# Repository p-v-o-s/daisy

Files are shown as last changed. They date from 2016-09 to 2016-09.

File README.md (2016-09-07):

#daisy

## arrangement

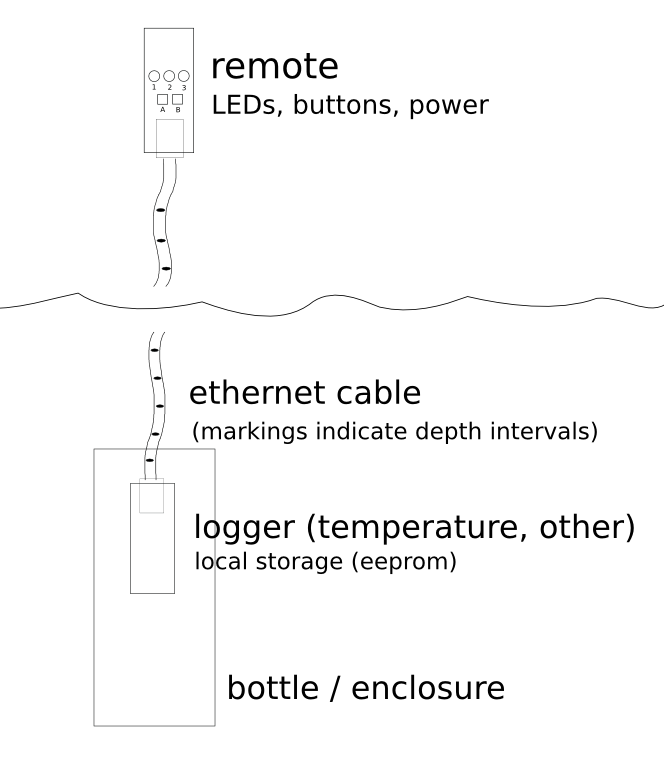
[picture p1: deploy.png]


# datalogger

Top:

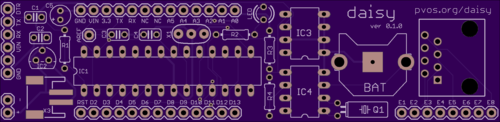
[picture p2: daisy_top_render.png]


Bottom:



- programmed via FTDI cable, board = "Arduino UNO"
- estimated < 100 microAmp sleep current
- DS1337 RTC with battery backup
- i2c EEPROM, 512KB storage
- RJ45 connector for 8-wire CAT-5,6,7 cable
- pin headers allow for patching RJ45 to digital / analog / power / ground
- JST header for battery power (or use remote)

# remote

Top:

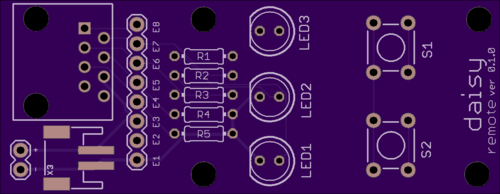
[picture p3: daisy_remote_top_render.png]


Bottom:

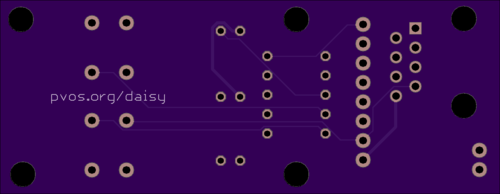
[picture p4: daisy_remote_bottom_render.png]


- RJ45 connector
- JST header for battery power (or use remote)
- RJ45 pins broken out via header for custom patching
- 3 LEDs connected to ethernet pins 1,2,3 (if placed)
- 2 momentary buttons connected to ethernet pins 4,5 (if placed)
- mounting holes 

# remote w/ display

Replaces LEDs with a 128x32 OLED display from Adafruit:

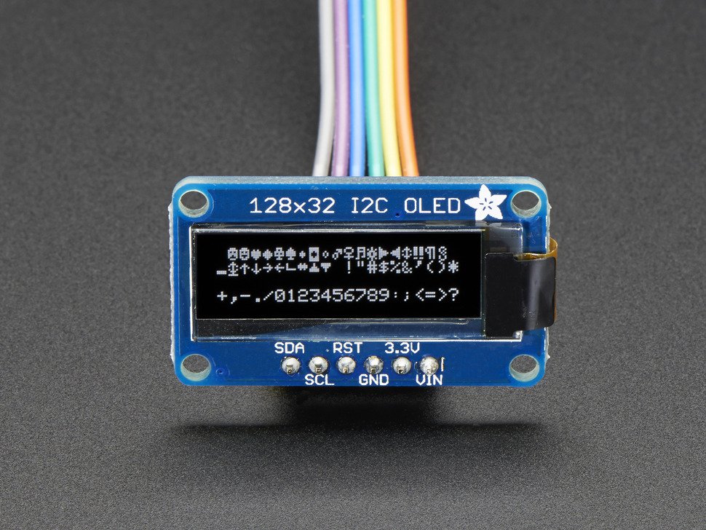
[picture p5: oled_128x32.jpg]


Top:

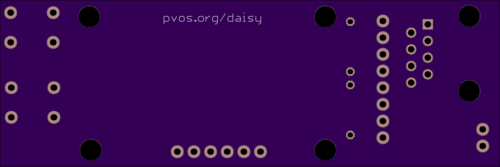
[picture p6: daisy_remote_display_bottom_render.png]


Bottom:

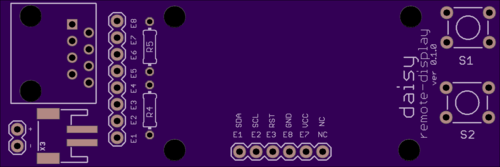
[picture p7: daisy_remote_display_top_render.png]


To hook up [Adafruit OLED display](https://www.adafruit.com/products/931):

- 3.3V  OLED VIN.
- GND to OLED ground (GND).
- I2C SCL (A5) to OLED SCL.
- I2C SDA (A4) to OLED SDA.
- digital 4 to OLED RST.
- these pins are marked on the remote-display board.  Proper relevant patching must be done on the logger, to match.

# ref

http://pinouts.ru/NetworkCables/ethernet_10_100_1000_pinout.shtml

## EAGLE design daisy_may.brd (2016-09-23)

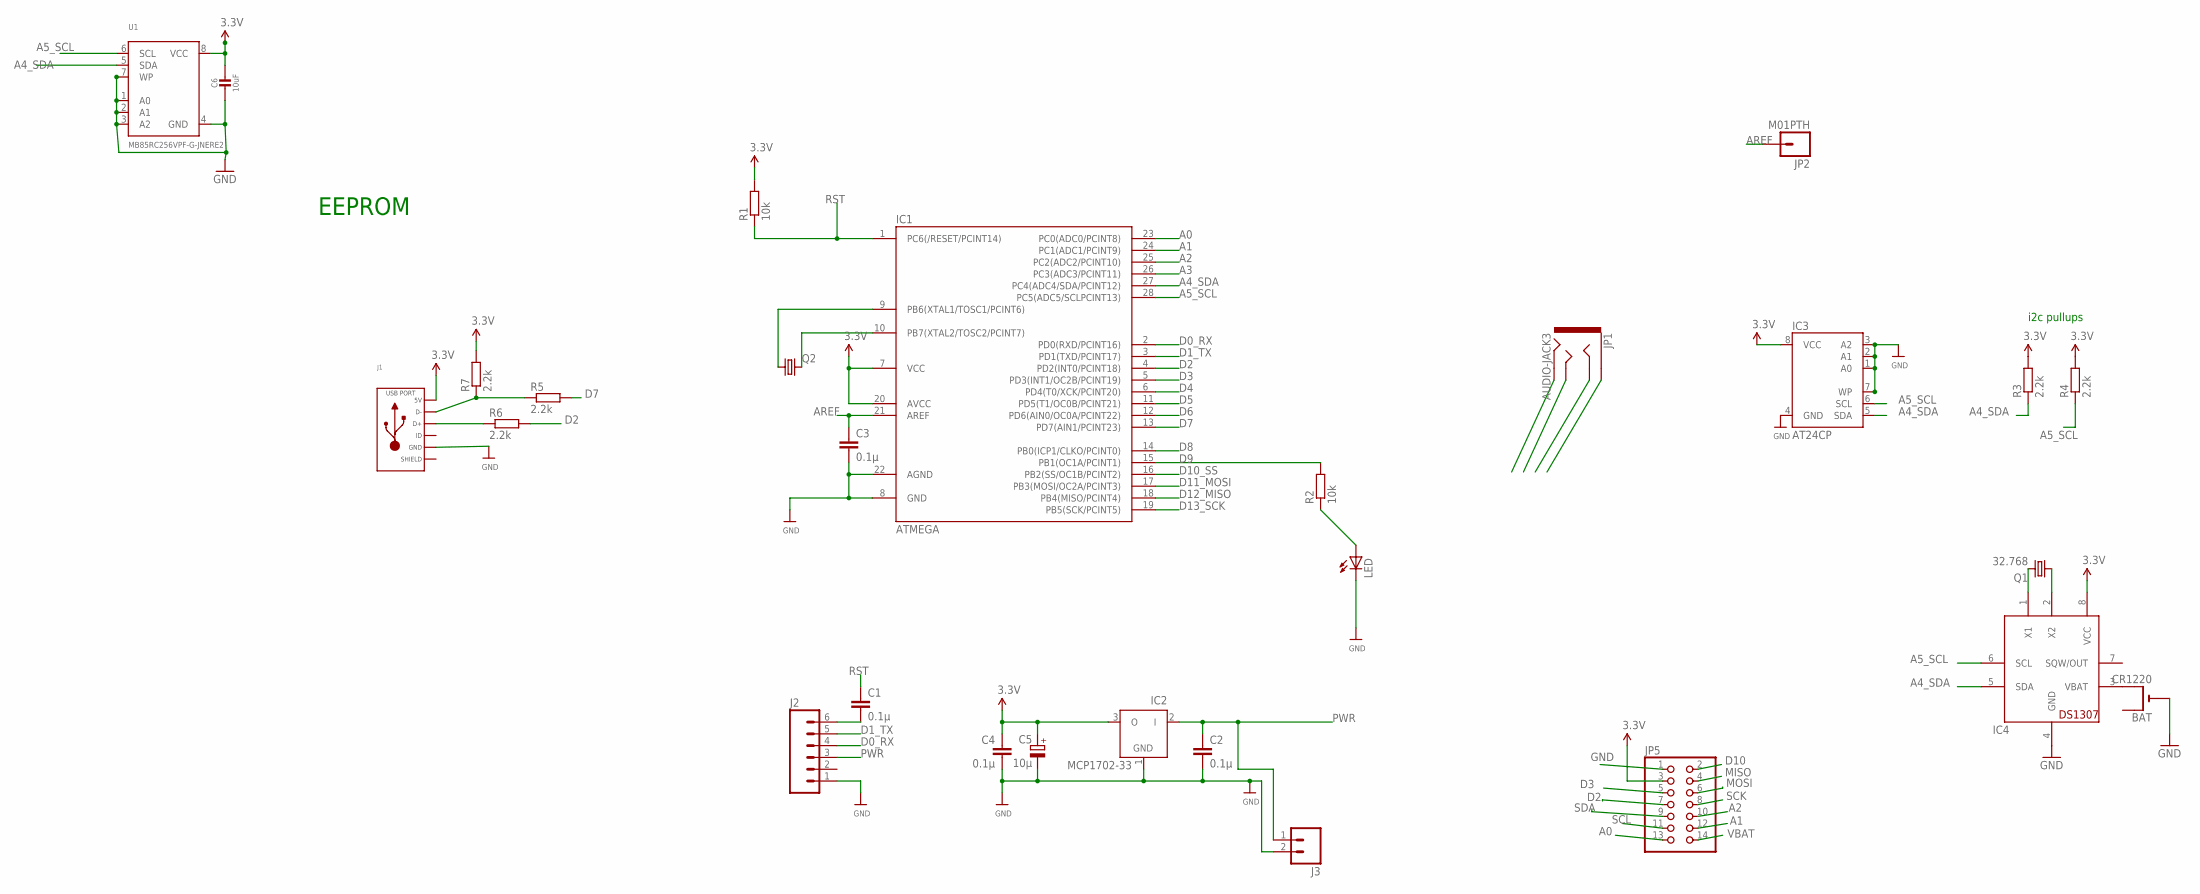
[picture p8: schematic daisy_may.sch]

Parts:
BAT: CR1220; CR1220-THM
C1, C2, C3, C4: 0.1µ; C025-024X044
C5: 10µ; E1,8-4
C6: 10uF; _0805MP
IC1: ATMEGA; DIL28-3
IC2: MCP1702-33; TO92
IC3: AT24CP; DIL08
IC4: DS1307; DIL08
J1: USB_MICRO_RIGHT; MICROUSB-RIGHT
J2: M06SILK_FEMALE_PTH; 1X06
J3: M02PTH; 1X02
JP1: AUDIO-JACK3; AUDIO-JACK-TRRS-SMD
JP2: M01PTH; 1X01
JP5: PINHD-2X7; 2X07
LED: LED3MM
Q1: 32.768; TC38H
Q2: CRYSTALHC49U70; HC49U70
R1, R2: 10k; 0204/7
R3, R4, R5, R6, R7: 2.2k; 0204/7
U1: MB85RC256VPF-G-JNERE2; SOIC8_208MIL

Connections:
A0: IC1.23 (PC0(ADC0/PCINT8)), JP5.13
A1: IC1.24 (PC1(ADC1/PCINT9)), JP5.12
A2: IC1.25 (PC2(ADC2/PCINT10)), JP5.10
A3: IC1.26 (PC3(ADC3/PCINT11))
A4_SDA: IC1.27 (PC4(ADC4/SDA/PCINT12)), IC3.5 (SDA), IC4.5 (SDA), R3.1, U1.5 (SDA)
A5_SCL: IC1.28 (PC5(ADC5/SCLPCINT13)), IC3.6 (SCL), IC4.6 (SCL), R4.1, U1.6 (SCL)
AREF: C3.1, IC1.21 (AREF), JP2.1
D0_RX: IC1.2 (PD0(RXD/PCINT16)), J2.4
D1_TX: IC1.3 (PD1(TXD/PCINT17)), J2.5
D2: IC1.4 (PD2(INT0/PCINT18)), JP5.7, R6.2
D3: IC1.5 (PD3(INT1/OC2B/PCINT19)), JP5.5
D4: IC1.6 (PD4(T0/XCK/PCINT20))
D5: IC1.11 (PD5(T1/OC0B/PCINT21))
D6: IC1.12 (PD6(AIN0/OC0A/PCINT22))
D7: IC1.13 (PD7(AIN1/PCINT23)), R5.2
D8: IC1.14 (PB0(ICP1/CLKO/PCINT0))
D9: IC1.15 (PB1(OC1A/PCINT1)), R2.2
D10: JP5.2
D10_SS: IC1.16 (PB2(SS/OC1B/PCINT2))
D11_MOSI: IC1.17 (PB3(MOSI/OC2A/PCINT3))
D12_MISO: IC1.18 (PB4(MISO/PCINT4))
D13_SCK: IC1.19 (PB5(SCK/PCINT5))
GND: BAT.-, C2.2, C3.2, C4.2, C5.-, C6.2, IC1.8 (GND), IC1.22 (AGND), IC2.1 (GND), IC3.1 (A0), IC3.2 (A1), IC3.3 (A2), IC3.4 (GND), IC3.7 (WP), IC4.4 (GND), J2.1, J3.2, JP5.1, LED.K (C), U1.1 (A0), U1.2 (A1), U1.3 (A2), U1.4 (GND), U1.7 (WP)
MISO: JP5.4
MOSI: JP5.6
unnamed: IC1.9 (PB6(XTAL1/TOSC1/PCINT6)), Q2.1
unnamed: LED.A, R2.1
unnamed: J1.2 (D-), R5.1, R7.1
unnamed: J1.3 (D+), R6.1
unnamed: IC4.1 (X1), Q1.2
unnamed: IC4.2 (X2), Q1.1
unnamed: C1.2, J2.6
unnamed: IC1.10 (PB7(XTAL2/TOSC2/PCINT7)), Q2.2
unnamed: BAT.+2 (+1), IC4.3 (VBAT)
PWR: C2.1, IC2.2 (I), J2.3, J3.1
RST: C1.1, IC1.1 (PC6(/RESET/PCINT14)), R1.1
SCK: JP5.8
SCL: JP5.11
SDA: JP5.9
SLD: J1.S1 (SLD), J1.S2 (SLD), J1.S3 (SLD), J1.S4 (SLD), J1.S5 (SLD), J1.S6 (SLD), J1.S7 (SLD), J1.S8 (SLD)
VBAT: JP5.14
VCC: C4.1, C5.+, C6.1, IC1.7 (VCC), IC1.20 (AVCC), IC2.3 (O), IC3.8 (VCC), IC4.8 (VCC), J1.1 (5V), JP5.3, R1.2, R3.2, R4.2, R7.2, U1.8 (VCC)

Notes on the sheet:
i2c pullups
EEPROM

Board: 2 copper layers, 28 parts (2 on the bottom side), 26 nets, no tracks yet.

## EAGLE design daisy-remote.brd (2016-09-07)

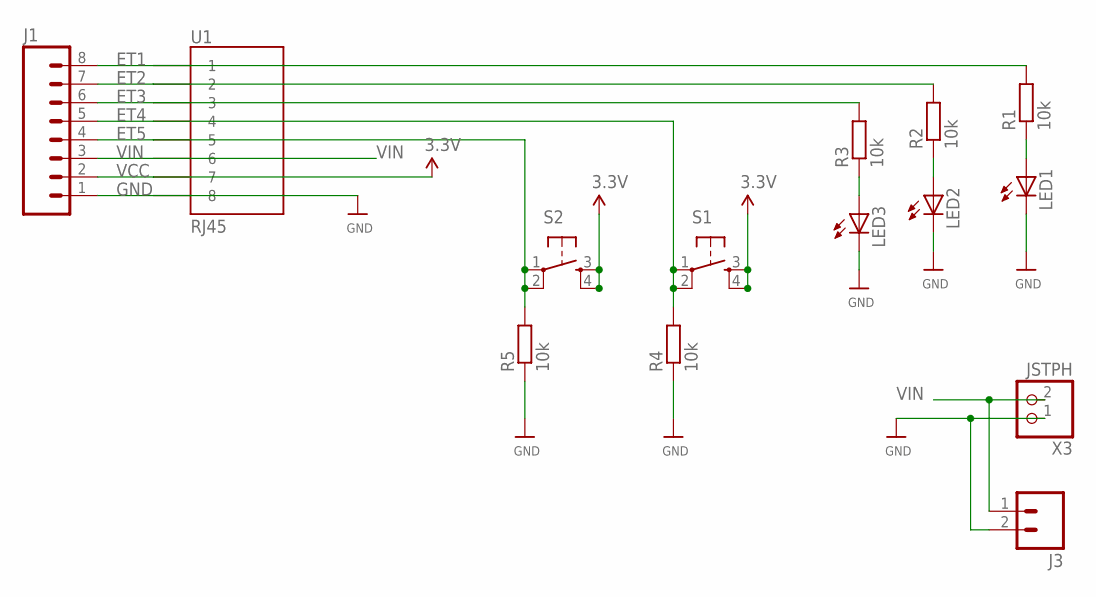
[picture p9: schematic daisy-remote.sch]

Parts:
J1: M08; 1X08_ROUND
J3: M02PTH; 1X02
LED1, LED2, LED3: LED5MM
R1, R2, R3, R4, R5: 10k; 0204/7
S1, S2: TAC_SWITCHPTH; TACTILE-PTH
U1: RJ45; RJ45-8
X3: JSTPH; JSTPH2

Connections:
ET1: J1.8, R1.2, U1.1
ET2: J1.7, R2.2, U1.2
ET3: J1.6, R3.2, U1.3
ET4: J1.5, R4.2, S1.1, S1.2, U1.4
ET5: J1.4, R5.2, S2.1, S2.2, U1.5
GND: J1.1, J3.2, LED1.K (C), LED2.K (C), LED3.K (C), R4.1, R5.1, U1.8, X3.1
unnamed: LED1.A, R1.1
unnamed: LED2.A, R2.1
unnamed: LED3.A, R3.1
VCC: J1.2, S1.3, S1.4, S2.3, S2.4, U1.7
VIN: J1.3, J3.1, U1.6, X3.2

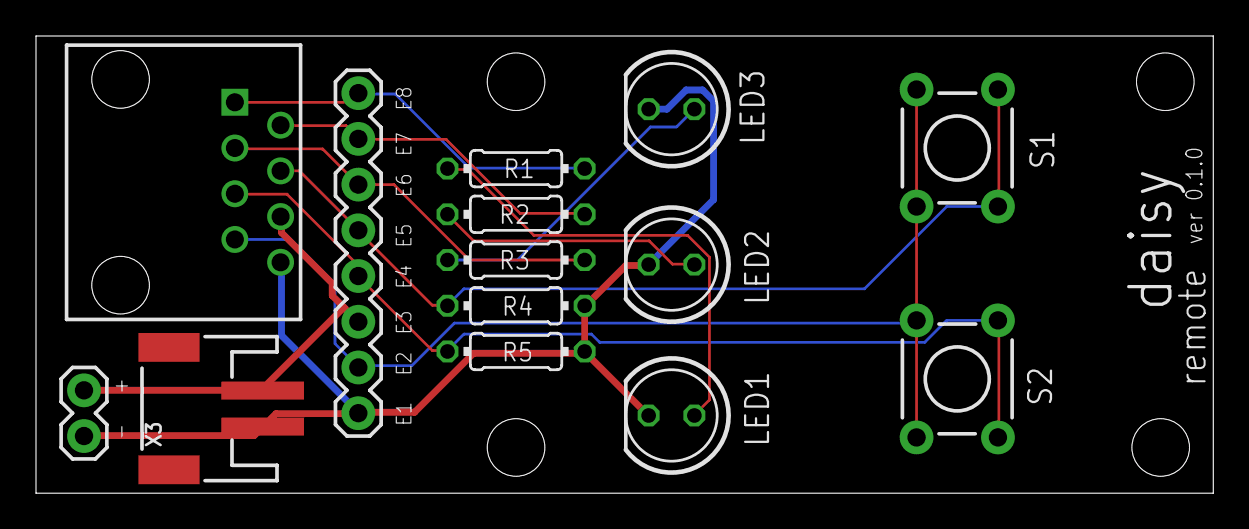
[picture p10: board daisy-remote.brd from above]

Board: 2 copper layers, 65.4 x 25.4 mm, 14 parts (0 on the bottom side), 11 nets.

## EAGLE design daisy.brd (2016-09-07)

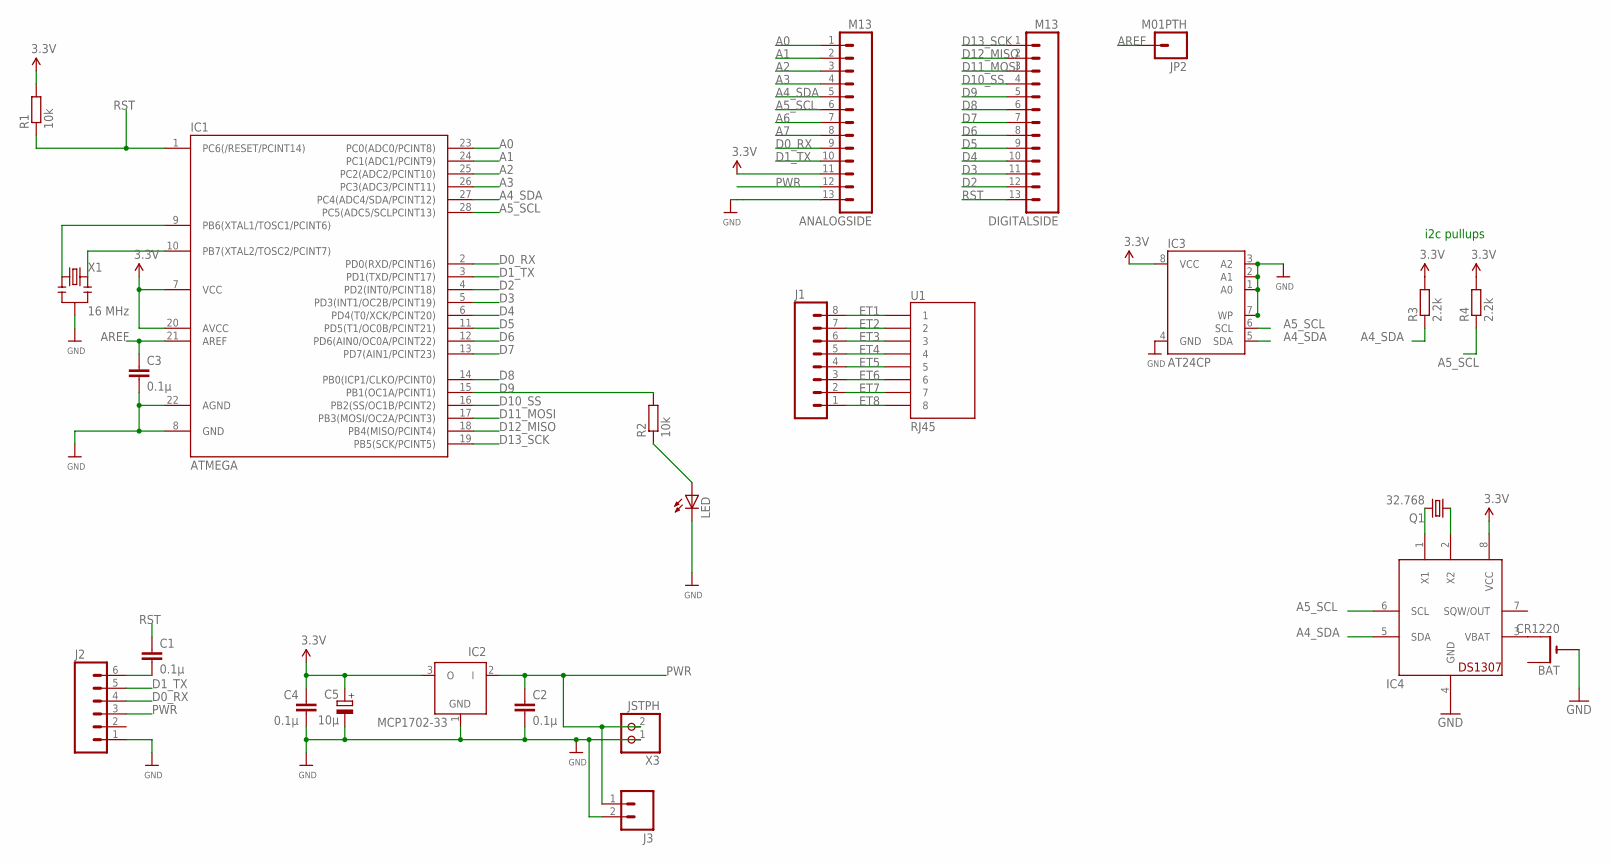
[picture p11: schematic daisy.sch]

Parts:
ANALOGSIDE: M13; 1X13
BAT: CR1220; CR1220-THM
C1, C2, C3, C4: 0.1µ; C025-024X044
C5: 10µ; E1,8-4
DIGITALSIDE: M13; 1X13
IC1: ATMEGA; DIL28-3
IC2: MCP1702-33; TO92
IC3: AT24CP; DIL08
IC4: DS1307; DIL08
J1: M08; 1X08_ROUND
J2: M06SILK_FEMALE_PTH; 1X06
J3: M02PTH; 1X02
JP2: M01PTH; 1X01
LED: LED3MM
Q1: 32.768; TC38H
R1, R2: 10k; 0204/7
R3, R4: 2.2k; 0204/7
U1: RJ45; RJ45-8
X1: 16 MHz; RESONATOR-PTH
X3: JSTPH; JSTPH2

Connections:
A0: ANALOGSIDE.1, IC1.23 (PC0(ADC0/PCINT8))
A1: ANALOGSIDE.2, IC1.24 (PC1(ADC1/PCINT9))
A2: ANALOGSIDE.3, IC1.25 (PC2(ADC2/PCINT10))
A3: ANALOGSIDE.4, IC1.26 (PC3(ADC3/PCINT11))
A4_SDA: ANALOGSIDE.5, IC1.27 (PC4(ADC4/SDA/PCINT12)), IC3.5 (SDA), IC4.5 (SDA), R3.1
A5_SCL: ANALOGSIDE.6, IC1.28 (PC5(ADC5/SCLPCINT13)), IC3.6 (SCL), IC4.6 (SCL), R4.1
A6: ANALOGSIDE.7
A7: ANALOGSIDE.8
AREF: C3.1, IC1.21 (AREF), JP2.1
D0_RX: ANALOGSIDE.9, IC1.2 (PD0(RXD/PCINT16)), J2.4
D1_TX: ANALOGSIDE.10, IC1.3 (PD1(TXD/PCINT17)), J2.5
D2: DIGITALSIDE.12, IC1.4 (PD2(INT0/PCINT18))
D3: DIGITALSIDE.11, IC1.5 (PD3(INT1/OC2B/PCINT19))
D4: DIGITALSIDE.10, IC1.6 (PD4(T0/XCK/PCINT20))
D5: DIGITALSIDE.9, IC1.11 (PD5(T1/OC0B/PCINT21))
D6: DIGITALSIDE.8, IC1.12 (PD6(AIN0/OC0A/PCINT22))
D7: DIGITALSIDE.7, IC1.13 (PD7(AIN1/PCINT23))
D8: DIGITALSIDE.6, IC1.14 (PB0(ICP1/CLKO/PCINT0))
D9: DIGITALSIDE.5, IC1.15 (PB1(OC1A/PCINT1)), R2.2
D10_SS: DIGITALSIDE.4, IC1.16 (PB2(SS/OC1B/PCINT2))
D11_MOSI: DIGITALSIDE.3, IC1.17 (PB3(MOSI/OC2A/PCINT3))
D12_MISO: DIGITALSIDE.2, IC1.18 (PB4(MISO/PCINT4))
D13_SCK: DIGITALSIDE.1, IC1.19 (PB5(SCK/PCINT5))
ET1: J1.8, U1.1
ET2: J1.7, U1.2
ET3: J1.6, U1.3
ET4: J1.5, U1.4
ET5: J1.4, U1.5
ET6: J1.3, U1.6
ET7: J1.2, U1.7
ET8: J1.1, U1.8
GND: ANALOGSIDE.13, BAT.-, C2.2, C3.2, C4.2, C5.-, IC1.8 (GND), IC1.22 (AGND), IC2.1 (GND), IC3.1 (A0), IC3.2 (A1), IC3.3 (A2), IC3.4 (GND), IC3.7 (WP), IC4.4 (GND), J2.1, J3.2, LED.K (C), X1.2, X3.1
unnamed: IC1.9 (PB6(XTAL1/TOSC1/PCINT6)), X1.1
unnamed: LED.A, R2.1
unnamed: IC4.1 (X1), Q1.2
unnamed: IC4.2 (X2), Q1.1
unnamed: C1.2, J2.6
unnamed: IC1.10 (PB7(XTAL2/TOSC2/PCINT7)), X1.3
unnamed: BAT.+2 (+1), IC4.3 (VBAT)
PWR: ANALOGSIDE.12, C2.1, IC2.2 (I), J2.3, J3.1, X3.2
RST: C1.1, DIGITALSIDE.13, IC1.1 (PC6(/RESET/PCINT14)), R1.1
VCC: ANALOGSIDE.11, C4.1, C5.+, IC1.7 (VCC), IC1.20 (AVCC), IC2.3 (O), IC3.8 (VCC), IC4.8 (VCC), R1.2, R3.2, R4.2

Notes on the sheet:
i2c pullups

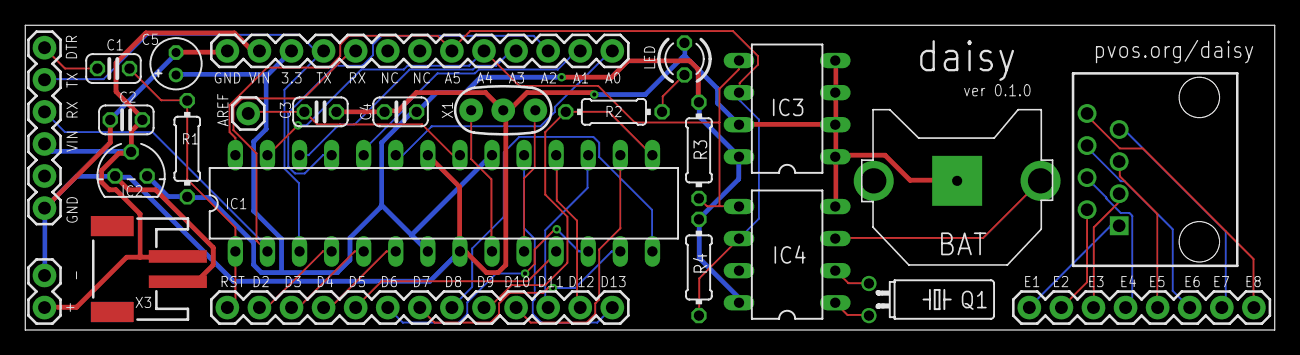
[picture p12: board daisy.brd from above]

Board: 2 copper layers, 98.9 x 24.1 mm, 25 parts (0 on the bottom side), 40 nets.

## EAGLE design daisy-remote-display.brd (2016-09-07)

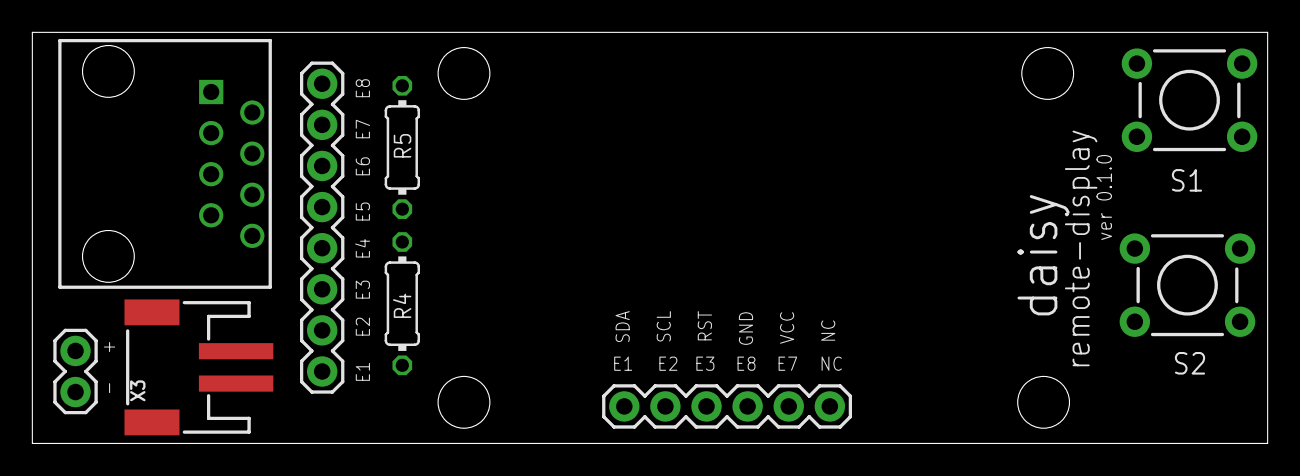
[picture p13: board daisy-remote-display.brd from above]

Board: 2 copper layers, 76.3 x 25.4 mm, 9 parts (0 on the bottom side), 8 nets, no tracks yet.

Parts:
J1: 1X08_ROUND
J3: 1X02
J4: 1X06
R4, R5: 10k; 0204/7
S1, S2: TACTILE-PTH
U1: RJ45; RJ45-8
X3: JSTPH; JSTPH2

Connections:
A4_SDA: J1.8, J4.1, U1.1
A5_SCL: J1.7, J4.2, U1.2
ET4: J1.5, R4.2, S1.1, S1.2, U1.4
ET5: J1.4, R5.2, S2.1, S2.2, U1.5
GND: J1.1, J3.2, J4.4, R4.1, R5.1, U1.8, X3.1
RST: J1.6, J4.3, U1.3
VCC: J1.2, J4.5, S1.3, S1.4, S2.3, S2.4, U1.7
VIN: J1.3, J3.1, U1.6, X3.2

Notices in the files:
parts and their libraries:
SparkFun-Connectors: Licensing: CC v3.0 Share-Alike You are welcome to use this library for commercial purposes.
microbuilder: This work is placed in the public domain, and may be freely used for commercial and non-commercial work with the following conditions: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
